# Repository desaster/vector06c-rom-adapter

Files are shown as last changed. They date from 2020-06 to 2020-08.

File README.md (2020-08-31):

# 2KB ROM Adapter for Vector-06C

To attach a 2KB rom to Vector-06c, normally you'd need to cut some traces and
add jumper wires. This mod attempts to eliminate the need to cut traces, and
minimizes the number of external wires.

Status: **~~UNTESTED~~, PROBABLY DANGEROUS ⚠️**

## How to build

1. Replace D9 on the V06C with a good dual wipe socket. Be careful, Vector-06C is delicate.
2. Add legs to the adapter board. Recommended to use thiner legs from "long leg female pin headers" to prevent damage to the socket.
3. Solder the two jumper wires of appropriate length to the adapter board, and connect them to the D1 chip on the Vector-06C.
4. Solder a double wipe socket to the adapter.
5. Add 2KB ROM chip to the adapter and enjoy.

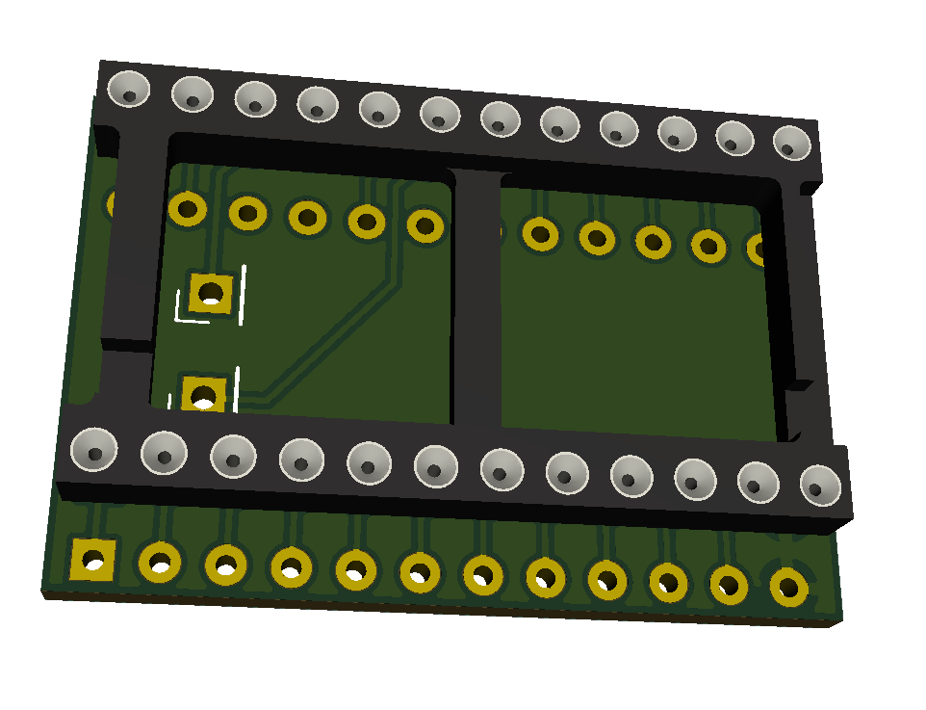
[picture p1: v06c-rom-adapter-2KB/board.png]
Vector-06C ROM Adapter


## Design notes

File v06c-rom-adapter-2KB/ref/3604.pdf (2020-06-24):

This Material Copyrighted By Its Respective Manufacturer

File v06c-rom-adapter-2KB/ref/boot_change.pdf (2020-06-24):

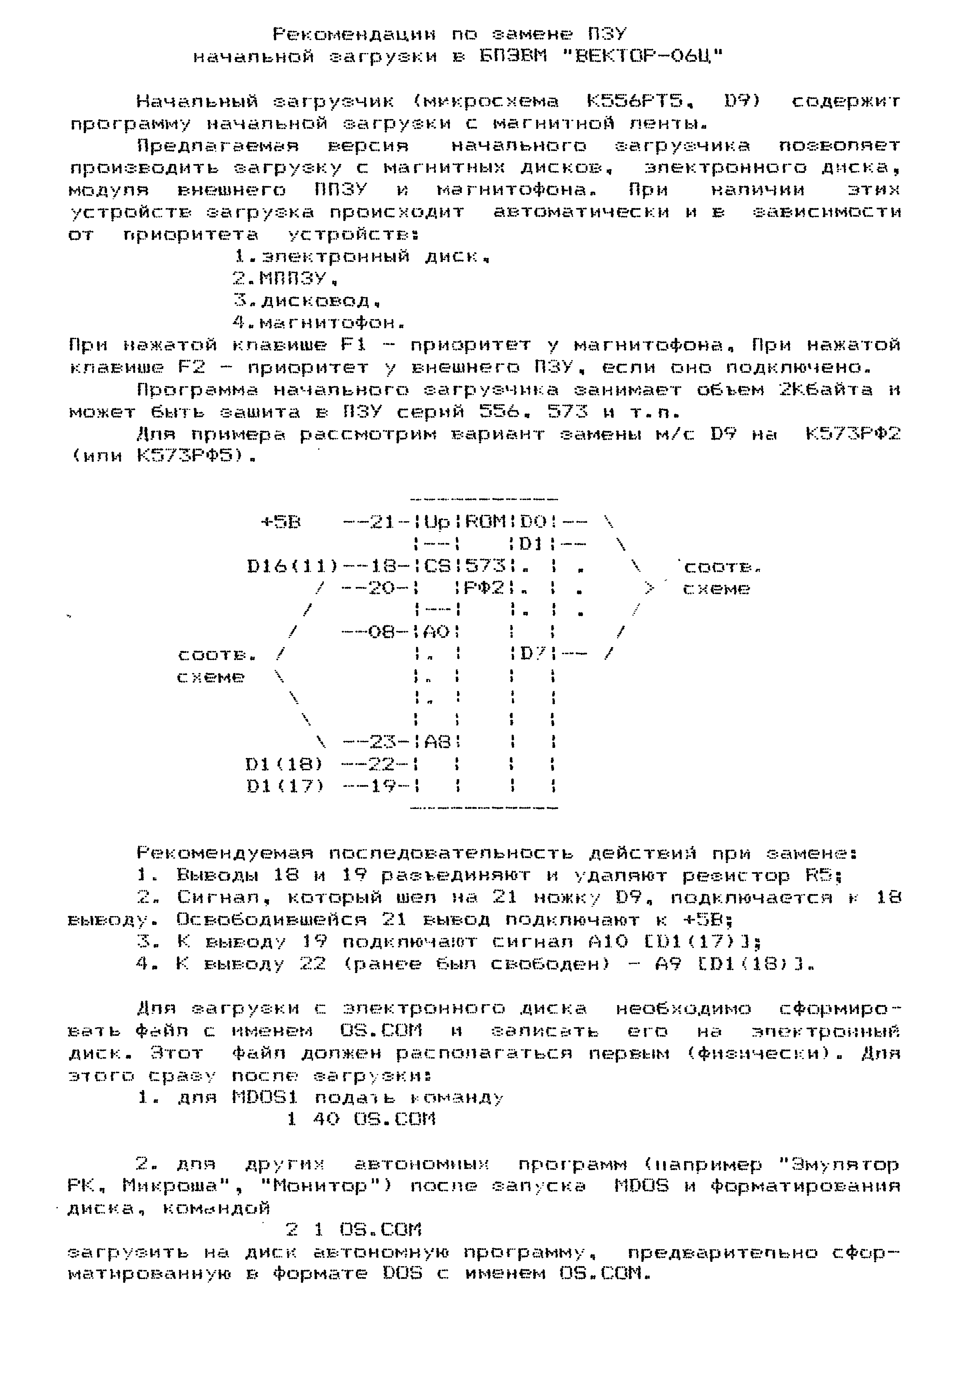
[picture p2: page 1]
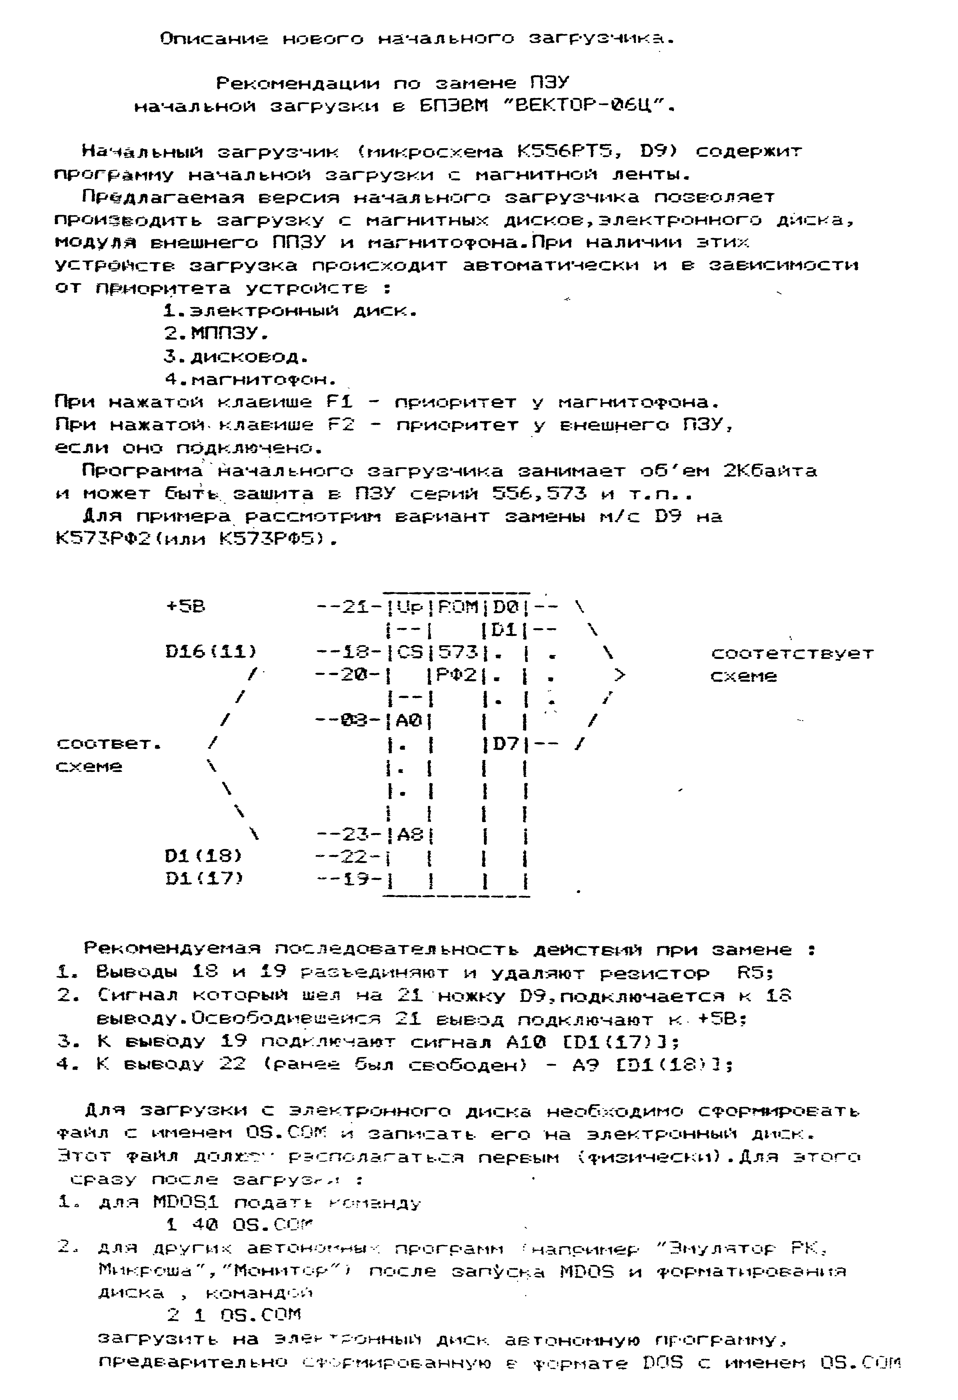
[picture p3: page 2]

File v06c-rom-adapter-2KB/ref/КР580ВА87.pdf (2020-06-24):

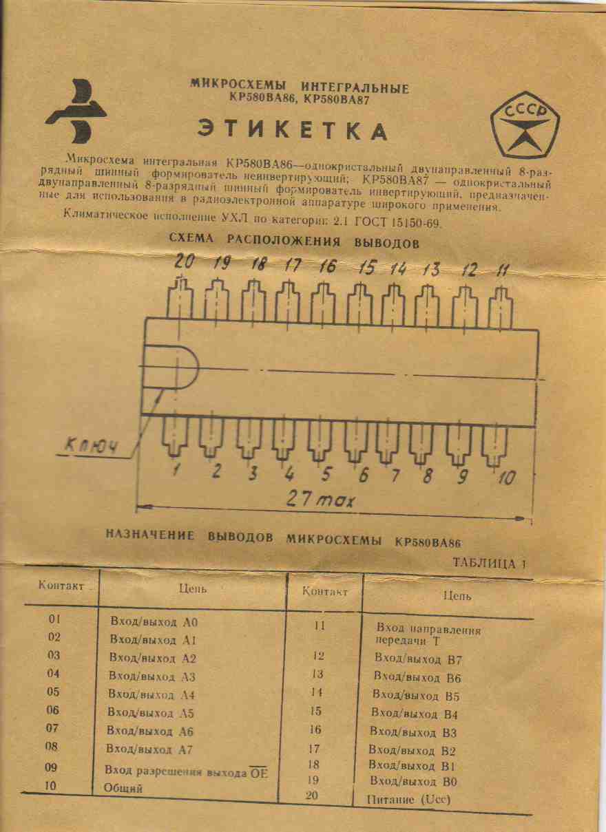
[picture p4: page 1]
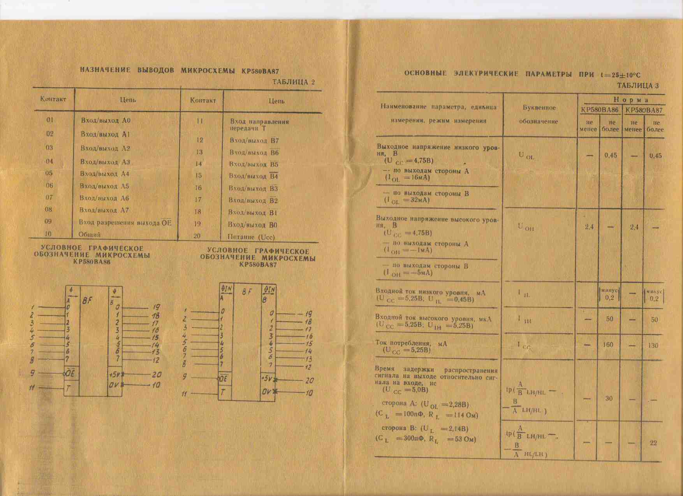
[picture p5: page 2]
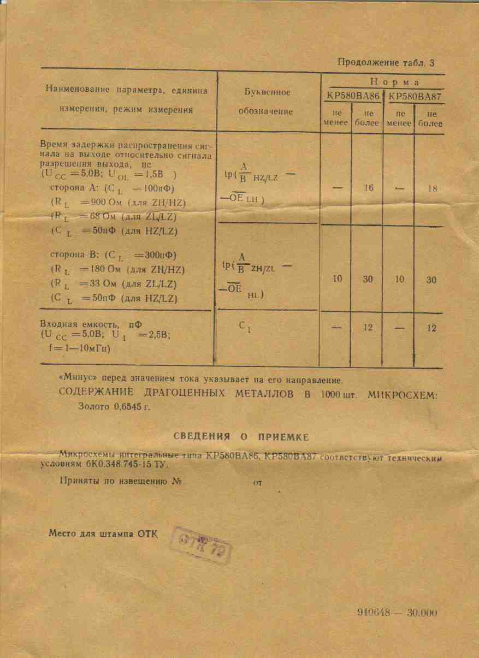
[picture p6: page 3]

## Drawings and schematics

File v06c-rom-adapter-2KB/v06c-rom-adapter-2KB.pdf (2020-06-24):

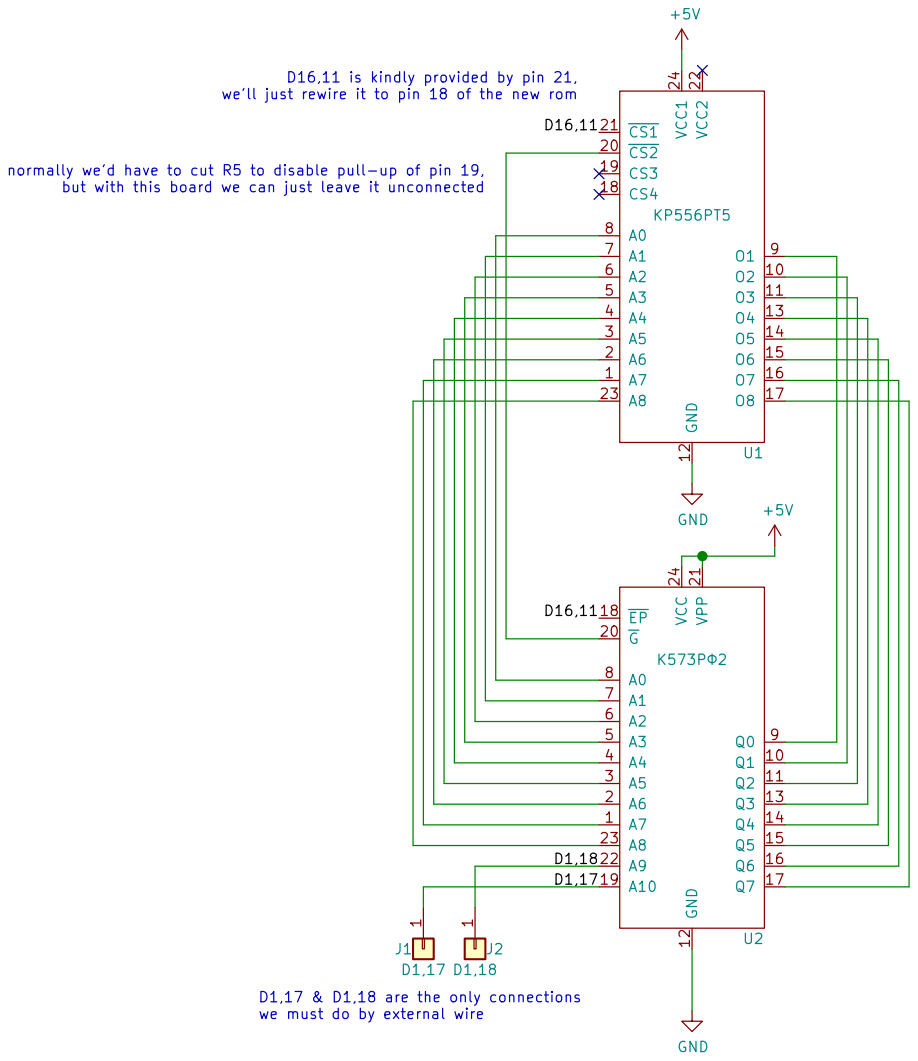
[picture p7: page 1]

D16,11 is kindly provided by pin 21,
we'll just rewire it to pin 18 of the new rom

normally we'd have to cut R5 to disable pull-up of pin 19,
but with this board we can just leave it unconnected

D1,17 & D1,18 are the only connections
we must do by external wire

File: v06c-rom-adapter-2KB.sch Sheet: /

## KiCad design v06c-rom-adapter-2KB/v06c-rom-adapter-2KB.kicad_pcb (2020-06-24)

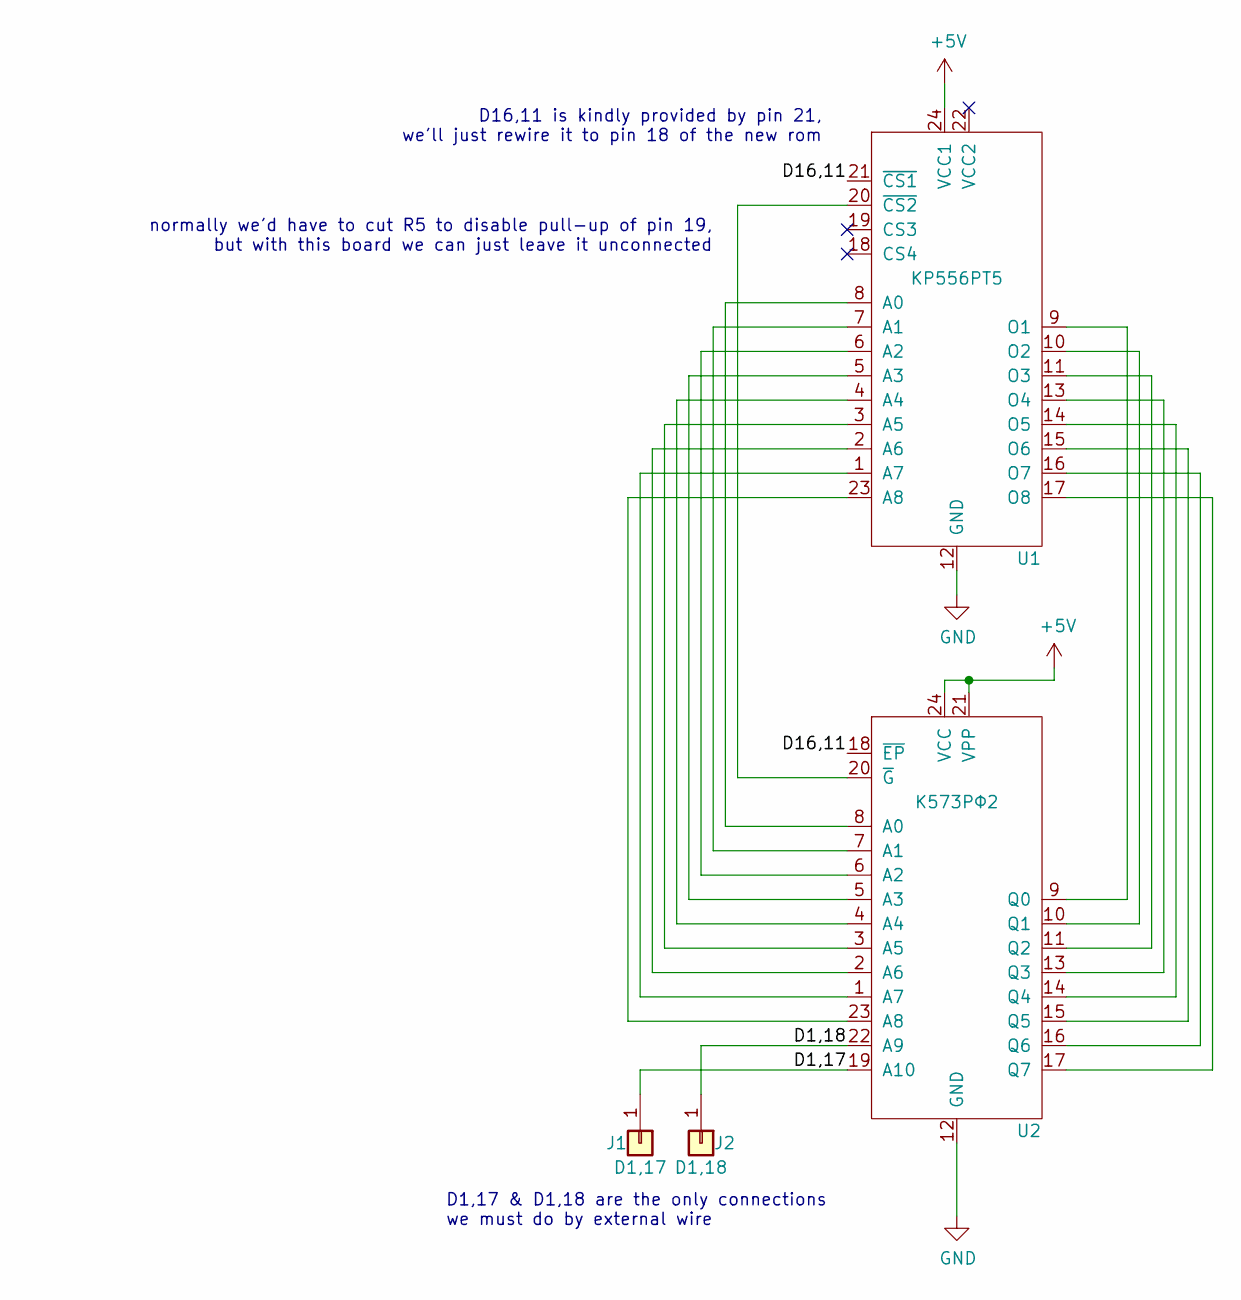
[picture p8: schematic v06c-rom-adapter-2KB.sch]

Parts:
J1: D1,17; PinHeader_1x01_P2.54mm_Vertical
J2: D1,18; PinHeader_1x01_P2.54mm_Vertical
U1: KP556PT5; DIP-24_W15.24mm_nosilk
U2: K573PФ2; DIP-24_W15.24mm_nosilk

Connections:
+5V: U1.24 (VCC1), U2.21 (VPP), U2.24 (VCC)
/D1,17: J1.1, U2.19 (A10)
/D1,18: J2.1, U2.22 (A9)
/D16,11: U1.21 (~CS1), U2.18 (~EP)
GND: U1.12 (GND), U2.12 (GND)
unnamed: U1.1 (A7), U2.1 (A7)
unnamed: U1.2 (A6), U2.2 (A6)
unnamed: U1.3 (A5), U2.3 (A5)
unnamed: U1.4 (A4), U2.4 (A4)
unnamed: U1.5 (A3), U2.5 (A3)
unnamed: U1.6 (A2), U2.6 (A2)
unnamed: U1.7 (A1), U2.7 (A1)
unnamed: U1.8 (A0), U2.8 (A0)
unnamed: U1.9 (O1), U2.9 (Q0)
unnamed: U1.10 (O2), U2.10 (Q1)
unnamed: U1.11 (O3), U2.11 (Q2)
unnamed: U1.13 (O4), U2.13 (Q3)
unnamed: U1.14 (O5), U2.14 (Q4)
unnamed: U1.15 (O6), U2.15 (Q5)
unnamed: U1.16 (O7), U2.16 (Q6)
unnamed: U1.17 (O8), U2.17 (Q7)
unnamed: U1.20 (~CS2), U2.20 (~G)
unnamed: U1.23 (A8), U2.23 (A8)

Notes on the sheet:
D16,11 is kindly provided by pin 21, we'll just rewire it to pin 18 of the new rom
D1,17 & D1,18 are the only connections we must do by external wire
normally we'd have to cut R5 to disable pull-up of pin 19, but with this board we can just leave it unconnected

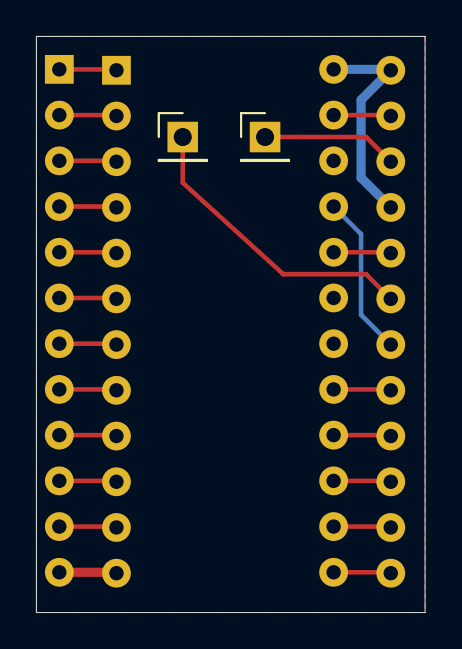
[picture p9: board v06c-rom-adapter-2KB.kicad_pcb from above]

Board: 2 copper layers, 21.6 x 32.0 mm, 4 parts (0 on the bottom side), 23 nets.

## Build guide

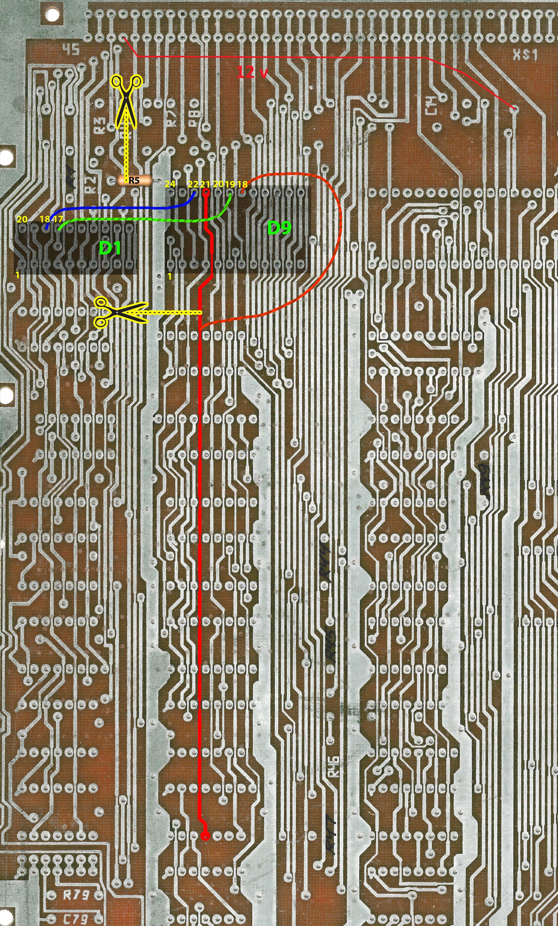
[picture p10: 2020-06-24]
v06c-rom-adapter-2KB/ref/wiring-front.jpg

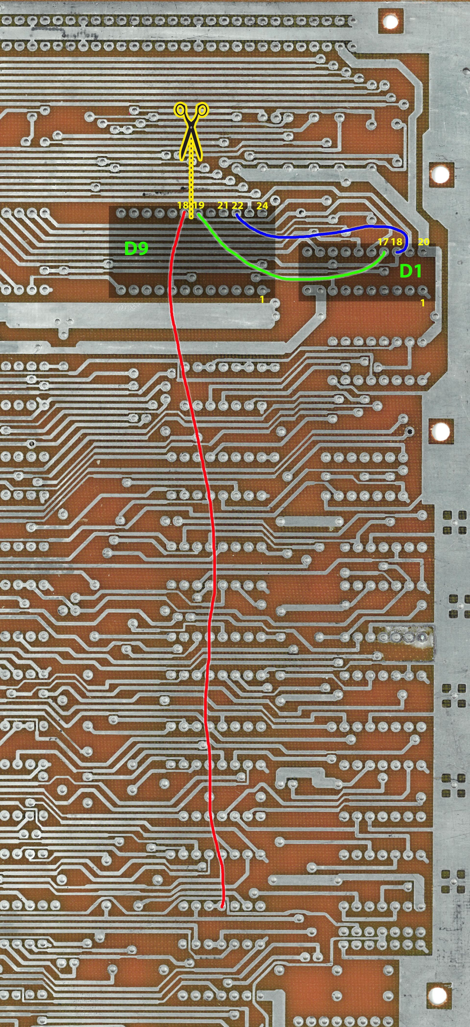
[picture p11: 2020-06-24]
v06c-rom-adapter-2KB/ref/wiring-back.jpg
